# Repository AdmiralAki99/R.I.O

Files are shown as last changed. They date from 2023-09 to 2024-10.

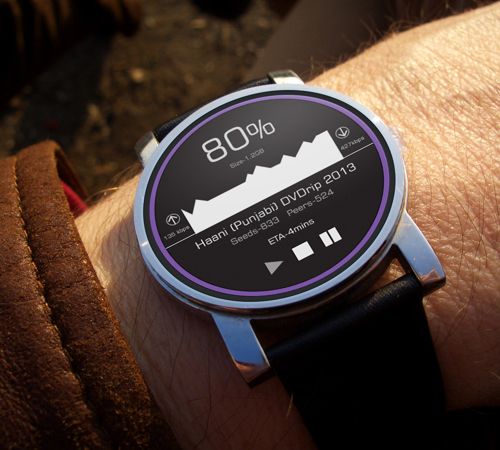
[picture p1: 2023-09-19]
src/test.jpg

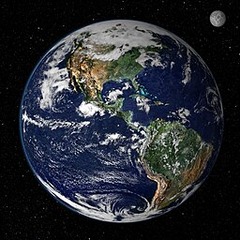
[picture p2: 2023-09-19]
src/space.jpg

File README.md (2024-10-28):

# Smartwatch Software

## Overview

A basic smartwatch software that is used for personal use and understanding how to read schematics, design PCB, understand embedded sytems.

## Render

https://github.com/user-attachments/assets/5ccf8013-91de-4bed-8570-e81a325c24fe

## Schematic
Schematic_page-0001

## Features

<ul>
    <li> BLE Communication With Swift Companion App</li>
    <li> Fits Inside 42mm Metal Watch Case </li>
</ul>

## Hardware Used
<ol>
    <li> ESP32 S3 MCU </li>
    <li> GC9A01 TFT Screen 1.28 Touch Screen </li>
    <li> Resistor (160k)</li>
    <li> Resistor (442k)</li>
    <li> 4 pin Magnetic Connector</li>
    <li> JST 2 Pin Connector RA</li>
    <li> Two Vertical Tactile Switch</li>
    <li>Schotky Diode </li>
</ol>

## Challenges Faced

<ul>
    <li> Understanding Schematics to connect the data pins and power pins to the magnetic connector to allow for flashing of the board </li>
    <li> Implementing BLE GATT Server & Characteristics</li>
    <li> Controlling power consumption to increase battery life </li>
    <li> Designing 3D housing for the watch to be placed inside the metal watch</li>
    <li> Designing PCB board using KiCad</li>
</ul>

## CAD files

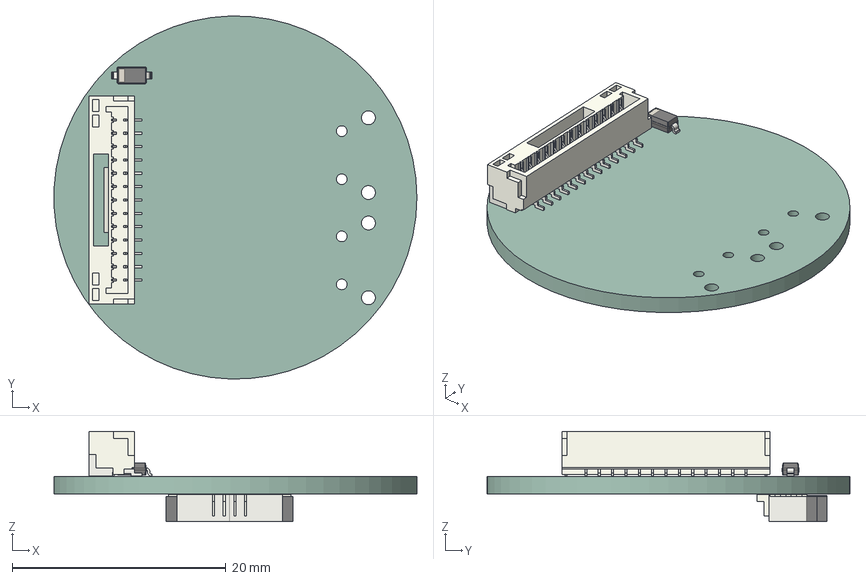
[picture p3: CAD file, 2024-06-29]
RIO_V1/RIO_V1.step
34.0 x 34.0 x 8.46 mm
JST_BM13B_GHS_TBT
D_SOD_123
TE_84952_4
RIO_V1 PCB

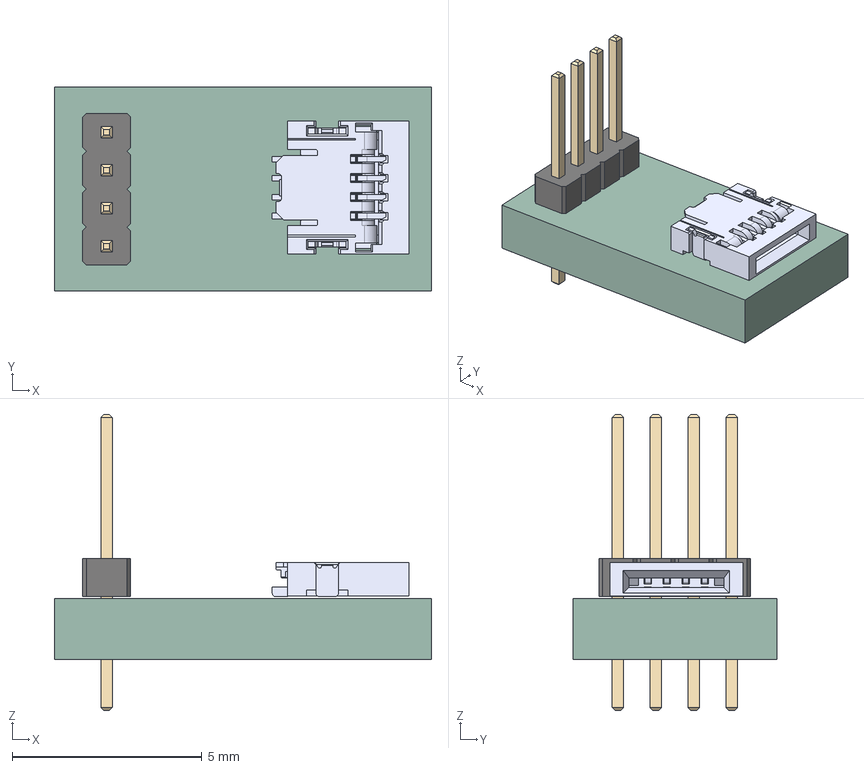
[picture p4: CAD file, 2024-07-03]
RIO_V1/Watch_Connector_V1/Watch_Connector_V1.step
9.93 x 5.38 x 7.80 mm
Watch_Connector_V1 1.1.1
PinHeader_1x04_P100mm_Vertical
Watch_Connector_V1 PCB

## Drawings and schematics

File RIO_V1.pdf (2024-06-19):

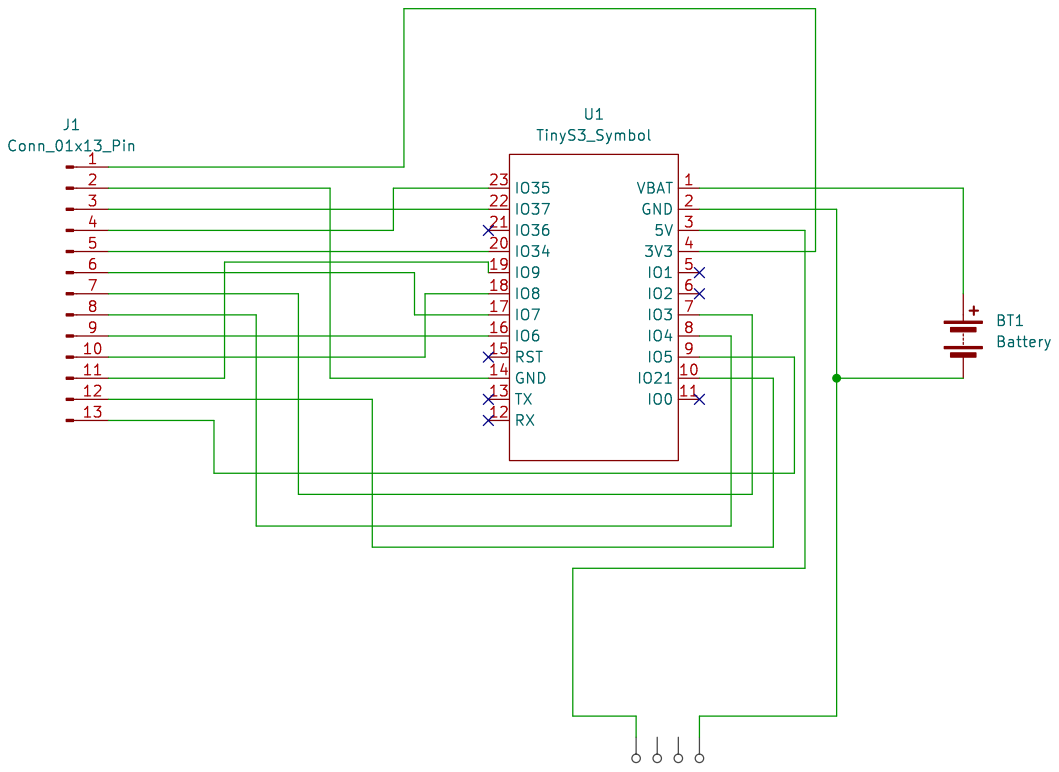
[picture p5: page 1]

Id: 1/1 Title: File: RIO_V1.kicad_sch Sheet: /

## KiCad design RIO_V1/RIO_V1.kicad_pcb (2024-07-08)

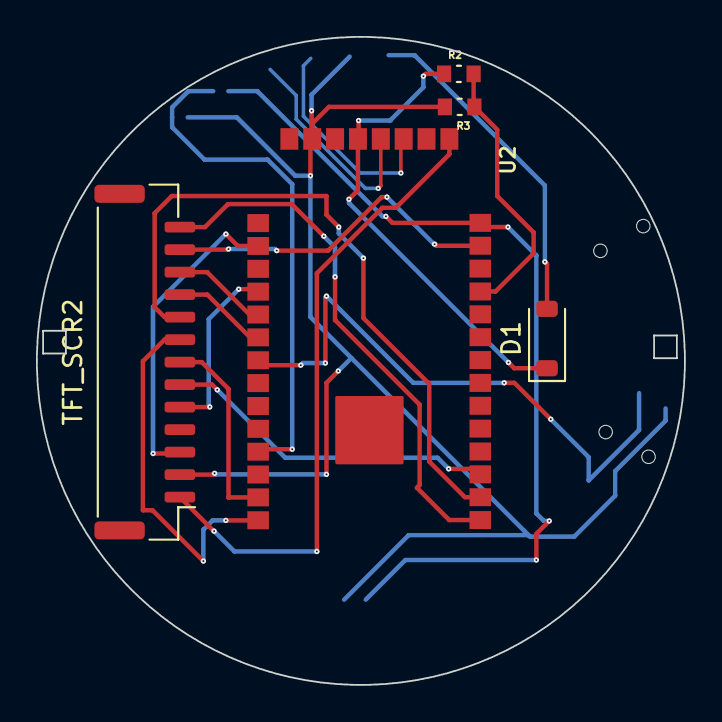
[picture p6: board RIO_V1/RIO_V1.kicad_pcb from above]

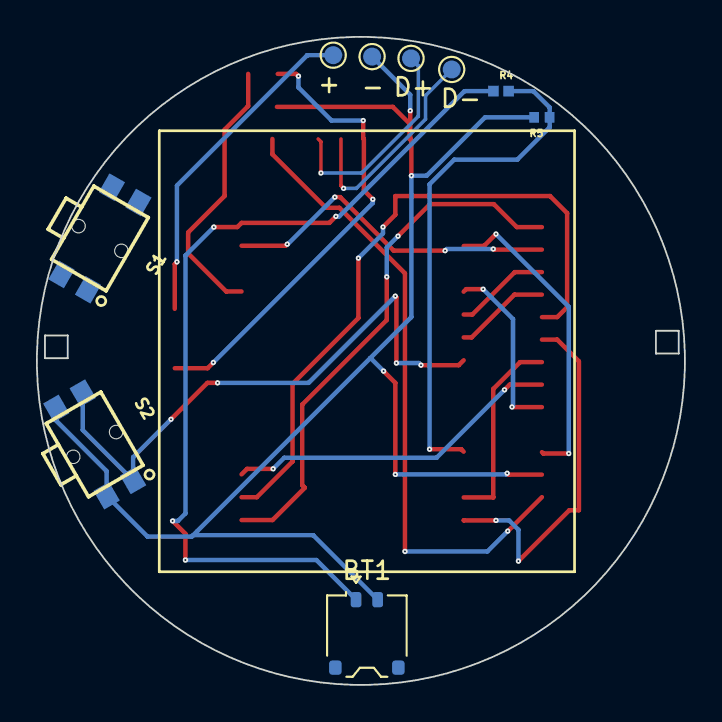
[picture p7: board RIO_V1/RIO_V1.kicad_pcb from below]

Board: 2 copper layers, 36.0 x 36.0 mm, 14 parts (9 on the bottom side), 22 nets.

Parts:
+: TestPoint; TestPoint_Pad_D1.0mm
-: TestPoint; TestPoint_Pad_D1.0mm
BT1: Battery; JST_ACH_BM02B-ACHSS-GAN-ETF_1x02-1MP_P1.20mm_Vertical
D1: MBR0530-TP; D_SOD-123
D+: TestPoint; TestPoint_Pad_D1.0mm
D-: TestPoint; TestPoint_Pad_D1.0mm
R2, R3: 50k; RESC1608X55N
R4: 442k; RESC1005X35N
R5: 160k; RESC1005X40N
S1, S2: TL1014BF160QG
TFT_SCR2: GH_CONNECTOR; JST_GH_BM13B-GHS-TBT_1x13-1MP_P1.25mm_Vertical
U2: NanoS3

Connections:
+3V3: TFT_SCR2.1, U2.8 (3v3)
+5V: D1.1 (K), R2.1, U2.4 (5V)
D+: D+.1, U2.6 (D+)
D-: D-.1, U2.5 (D-)
GND: -.1, BT1.2 (-), R3.2, R5.2, S1.1, S1.3, S2.2, S2.4, TFT_SCR2.2, U2.2 (GND)
IO0: S2.1, S2.3, U2.29 (IO0)
IO1: R4.2, R5.1, U2.33 (IO1)
IO3: TFT_SCR2.7, U2.35 (IO3)
IO4: TFT_SCR2.8, U2.36 (IO4)
IO5: TFT_SCR2.13, U2.22 (IO5)
IO6: TFT_SCR2.9, U2.21 (IO6)
IO7: TFT_SCR2.6, U2.20 (IO7)
IO8: TFT_SCR2.10, U2.28 (IO8)
IO9: TFT_SCR2.11, U2.27 (IO9)
IO17: R2.2, R3.1, U2.12 (IO17)
IO21: TFT_SCR2.12, U2.10 (IO21)
IO34: TFT_SCR2.5, U2.26 (IO34)
IO35: TFT_SCR2.4, U2.23 (IO35)
IO37: TFT_SCR2.3, U2.24 (IO37)
unnamed: +.1, D1.2 (A)
RESET: S1.2, S1.4, U2.3 (RESET)
VBAT: BT1.1 (+), R4.1, U2.9 (VBAT)

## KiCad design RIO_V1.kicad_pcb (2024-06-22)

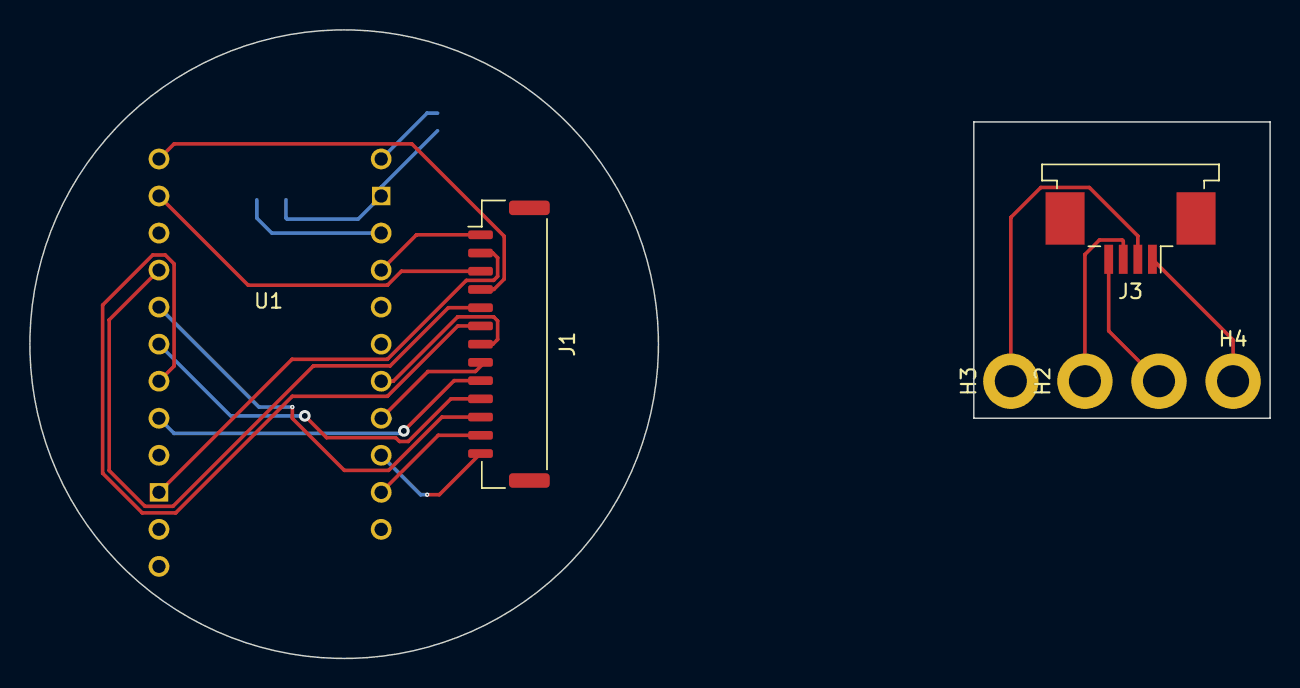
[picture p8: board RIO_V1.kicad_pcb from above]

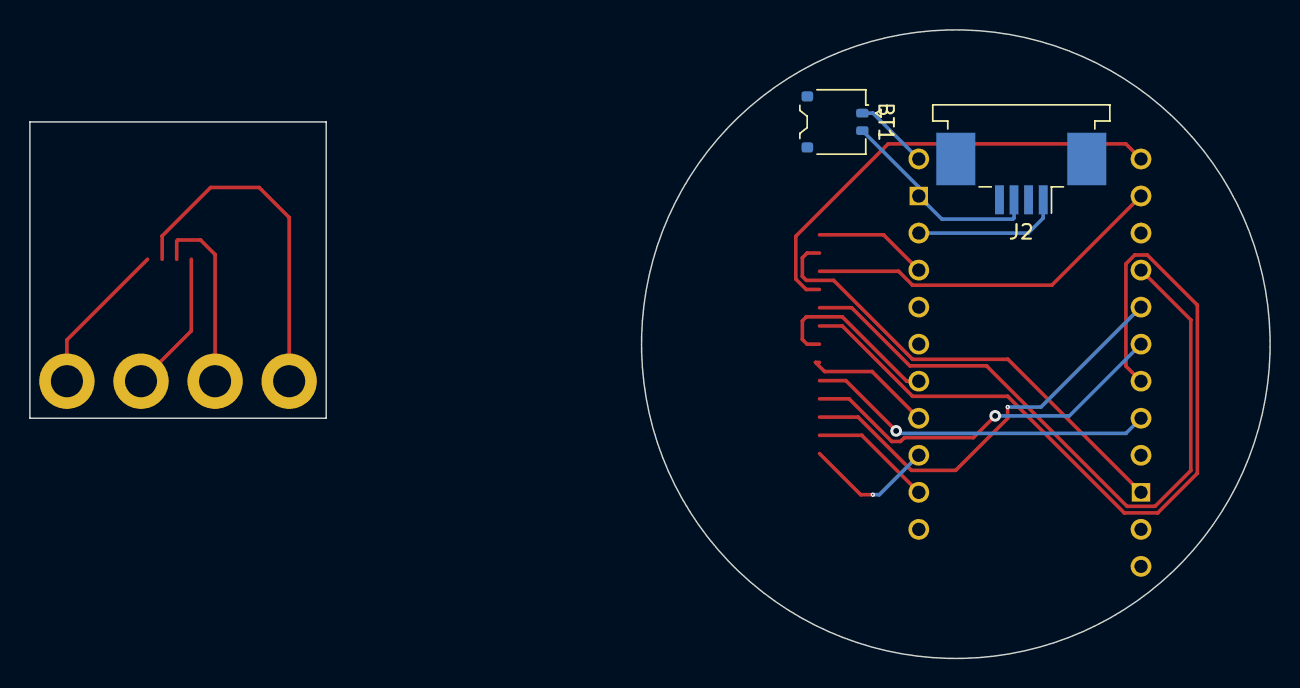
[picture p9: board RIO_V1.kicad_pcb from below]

Board: 2 copper layers, 85.1 x 43.1 mm, 9 parts (2 on the bottom side), 20 nets.

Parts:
BT1: Battery; JST_ACH_BM02B-ACHSS-GAN-ETF_1x02-1MP_P1.20mm_Vertical
H1: Pin_2; MountingHole_2.2mm_M2_DIN965_Pad
H2: Pin_3; MountingHole_2.2mm_M2_DIN965_Pad
H3, H4: Pin_4; MountingHole_2.2mm_M2_DIN965_Pad
J1: Conn_01x13_Pin; JST_GH_BM13B-GHS-TBT_1x13-1MP_P1.25mm_Vertical
J2: Conn_01x03_Pin; TE_84952-4_1x04-1MP_P1.0mm_Horizontal
J3: Conn_01x04_Pin; TE_84952-4_1x04-1MP_P1.0mm_Horizontal
U1: TinyS3_Symbol; TinyS3

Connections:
unnamed: BT1.1 (+), U1.1 (VBAT)
unnamed: BT1.2 (-), J2.3, U1.2 (GND)
unnamed: J1.1, U1.4 (3V3)
unnamed: J1.2, U1.14 (GND)
unnamed: J1.3, U1.22 (IO37)
unnamed: J1.4, U1.23 (IO35)
unnamed: J1.5, U1.20 (IO34)
unnamed: J1.6, U1.17 (IO7)
unnamed: J1.7, U1.7 (IO3)
unnamed: J1.8, U1.8 (IO4)
unnamed: J1.9, U1.16 (IO6)
unnamed: J1.10, U1.18 (IO8)
unnamed: J1.11, U1.19 (IO9)
unnamed: J1.12, U1.10 (IO21)
unnamed: J1.13, U1.9 (IO5)
unnamed: J2.1, U1.3 (5V)
unnamed: H4.1, J3.1
unnamed: H3.1, J3.2
unnamed: H2.1, J3.3
unnamed: H1.1, J3.4

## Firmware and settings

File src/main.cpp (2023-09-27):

#include "settings_screen.h"
#include "parsecs.h"
#include "time_screen.h"
#include <TFT_eSPI.h>
#include <lvgl.h>
#include <CST816S.h>
#include <driver/gpio.h>
#include <Ticker.h>
#include <WiFi.h>
#include <esp_bt.h>
#include "driver/adc.h"

time_t current_time;

void setup() {
  // put your setup code here, to run once:

  pinMode(LCD_BL_PIN,OUTPUT);

  digitalWrite(LCD_BL_PIN,HIGH);

  // touch.begin();

  // /**
  //  * Initialize the TFT_eSPI Drivers
  //  * */
  // tft.init();
  // tft.setRotation(0);

  init_watch();

  init_ble_server();

  // tft.fillScreen(TFT_WHITE);

  // xTaskCreatePinnedToCore(sendMessage(&message[0],7),"Send Message",10000,NULL,1,&bluetooth_task_handle,1);

  // tft.fillScreen(TFT_WHITE);
  // Serial.begin(115200);


  /**
   * Initialize LVGL Library and Functions
   **/

  // a2dp_sink.start("ESP32 A2DP Sink");
  // a2dp_sink.set_avrc_metadata_callback(avrc_metadata_callback);
  // lv_init();

  // // lv_disp_buf_init(&draw_buf,buf_1,NULL,240*10); 
  // lv_disp_draw_buf_init(&draw_buf, buf_1, NULL, 240 * 10);//Initialize Display Buffer

  // static lv_disp_drv_t disp_drv;
  // lv_disp_drv_init(&disp_drv);

  // disp_drv.hor_res = screenWidth;
  // disp_drv.ver_res = screenHeight;
  // disp_drv.flush_cb = flush_display;
  // disp_drv.draw_buf = &draw_buf;
  // lv_disp_drv_register(&disp_drv);

  // //todo: Add Touch Functions and Displays to LVGL

  // static lv_indev_drv_t indev_drv;
  // lv_indev_drv_init(&indev_drv);
  // indev_drv.type = LV_INDEV_TYPE_POINTER;
  // indev_drv.read_cb = touchpad_event;
  // lv_indev_t* touchpad = lv_indev_drv_register(&indev_drv);

  // // display_watch_dial(lv_scr_act());

  // // Create a style for the waveform
  // /* Create a container object */
  //   // lv_obj_t * label;


  /**
   * Creating the Background Dial Style and Button
   * */

  main_screen = lv_obj_create(NULL);
  /**
   * Creating a watch second and minute hands and hour hands
   * 
   **/
  
  current_time = time(nullptr);

  init_screen(main_screen);

  // lv_style_t transp_button;

  // lv_style_init(&transp_button);
  // lv_style_set_bg_opa(&transp_button,LV_STATE_DEFAULT,0);
  // lv_style_set_border_width(&transp_button,LV_STATE_DEFAULT,0);
  // lv_style_set_outline_width(&transp_button,LV_STATE_DEFAULT,0);

  // btn = lv_btn_create(time_screen,NULL);
  // lv_obj_align(btn,NULL,LV_ALIGN_IN_TOP_MID,0,0);
  // lv_obj_add_style(btn,LV_BTN_PART_MAIN,&transp_button);
  // lv_obj_set_style_local_bg_color(btn,LV_BTN_PART_MAIN,LV_STATE_DEFAULT,LV_COLOR_BLACK);
  // lv_obj_set_style_local_value_str(btn,LV_OBJ_PART_MAIN,LV_STATE_DEFAULT,"Button");
  // lv_obj_set_style_local_value_color(btn,LV_OBJ_PART_MAIN,LV_STATE_DEFAULT,LV_COLOR_WHITE);
  // lv_obj_set_event_cb(btn,test_cb);

  // lv_obj_t *back_icon = lv_img_create(btn, NULL);
  // lv_img_set_src(back_icon, LV_SYMBOL_LEFT);
  // lv_obj_set_size(back_icon, 20, 20);
  // lv_obj_set_pos(back_icon, 10, 5);
  // lv_obj_set_style_local_text_color(back_icon, LV_LABEL_PART_MAIN, LV_STATE_DEFAULT, LV_COLOR_WHITE); // Set the icon color to white

  // init_music_screen(main_screen);

  // init_settings_screen(main_screen);

  lv_scr_load(main_screen);
  
  gpio_config_t io_conf;
  io_conf.intr_type = GPIO_INTR_DISABLE;
  io_conf.mode = GPIO_MODE_INPUT;
  io_conf.pin_bit_mask = 1ULL <<GPIO_NUM_0;
  io_conf.pull_down_en = GPIO_PULLDOWN_DISABLE;
  io_conf.pull_up_en = GPIO_PULLUP_ENABLE;
  gpio_config(&io_conf);
  //todo: Create circular line meter for battery level

  Serial.print(touch.data.version);
  Serial.print("\t");
  Serial.print(touch.data.versionInfo[0]);
  Serial.print("-");
  Serial.print(touch.data.versionInfo[1]);
  Serial.print("-");    
  Serial.println(touch.data.versionInfo[2]);

  // lv_obj_t *img_obj = lv_img_create(lv_scr_act());

  // lv_img_set_src(img_obj,"A:src/space.jpg");

  lv_scr_load(main_screen);
  initTimer();

  // Serial.begin(115200);
  // Serial.println(xPortGetCoreID());
}

void loop() {
  // Open a large JPEG image stored in FLASH memory (included as thumb_test.h)
  // This image is 12 megapixels, but has a 320x240 embedded thumbnail in it

  // put your main code here, to run repeatedly

  // sendMessage(&message[0],7);

  // Serial.println(xPortGetCoreID());
  

  lv_scr_load(lv_scr_act());

  lv_task_handler();
  lv_timer_handler();

  current_time = now();

  update_screen(current_time);

  // Serial.println(String(touch.gesture().c_str()));

  // advertise_ble_server();


  // if(gpio_get_level(GPIO_NUM_0) == 0)
  // {
  //   Serial.println("Button Pressed");
  // }

  // if(play_button_task != NULL)
  // {
  //   // Serial.println( "Play Button Task is not NULL");
  // }else{
  //   Serial.println("Play Button Task is NULL");
  // }

  lv_tick_inc(1);
  // update_music_screen();

  // vTaskDelay(pdMS_TO_TICKS(16));

  // delay(1000);
  
}

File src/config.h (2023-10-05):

#pragma once

#include <FS.h>
#include <TFT_eSPI.h>
#include <lvgl.h>
#include <CST816S.h>
#include <driver/gpio.h>
#include <Ticker.h>
#include <WiFi.h>
#include <TinyGPSPlus.h>
#include <SoftwareSerial.h>
#include <TimeLib.h>

#include "freertos/FreeRTOS.h"
#include "freertos/task.h"

#include "ble_config.h"

#define LV_COLOR_BLACK  LV_COLOR_MAKE(0x00, 0x00, 0x00)
#define LV_COLOR_WHITE LV_COLOR_MAKE(0xFF, 0xFF, 0xFF)
#define LV_COLOR_GREY LV_COLOR_MAKE(0x80, 0x80, 0x80)

#define SERVICE_UUID "4fafc201-1fb5-459e-8fcc-c5c9c331914b"
#define CHARACTERISTIC_UUID "beb5483e-36e1-4688-b7f5-ea07361b26a8"
#define TIME_CHARACTERISTIC_UUID "b9dc3d38-4b22-11ee-be56-0242ac120002"
#define TODO_CHARACTERISTIC_UUID "28bd3c28-635d-11ee-8c99-0242ac120002"

/**
 * Pin Definitions for GC9A01 TFT SCREEN
*/

#define MISO_PIN 37
#define MOSI_PIN 35
#define SCLK_PIN 34
#define LCD_CS_PIN 7
#define LCD_DC_PIN 3
#define LCD_RST_PIN 4
#define LCD_BL_PIN 6
#define TP_SDA_PIN 8
#define TP_SCL_PIN 9
#define TP_INT_PIN 21
#define TP_RST_PIN 5

/**
 * Pin Definitions for the GPS Module
*/

#define GPS_RX_PIN 2
#define GPS_TX_PIN 36

/**
 * Declaring the Global Variables that will be used commonly
*/

lv_obj_t* main_screen;

TinyGPSPlus gps = TinyGPSPlus();
SoftwareSerial ss(GPS_RX_PIN, GPS_TX_PIN);

#define ANALOG_WATCH_FACE

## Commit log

2023-09-19 Fixed Bug
    Removed bug that stopped interaction
    [main.cpp]
2023-09-24 Added Method to Signal State of Music Playback
    Added simple method to send music playback to device to indicate if track needs to be skipped or rewinded. Need to create method to encode message and decode encoded messages
    [music_screen.h, parsecs.h]
2023-09-26 Created Video Source enum class
    Created Video Source enum class to track state of playback
2023-09-26 Fixed System Error
    Fixed system error that did not left Touch screen to be drawn
    [parsecs.h]
2023-09-27 Created a 200x200 to display frames
    Created a 200x200 canvas to display frames. Size restricted due size of RAM available. Need to try projecting decoded JPEG images
2023-10-02 Removed and Changed BLE Functionality
    Removed and changed BLE functionality to remove the initial values as well as remove the case where my mistake caused multiple transmissions to App
    [parsecs.h]
2023-10-02 Changed Function Calls to Display Metadata
    Changed function calls to change the way the music metadata is displayed on the device and removed the error where music labels were concatenated instead of repalced
    [music_screen.h]
2023-10-04 Added Functionality To Receive Tasks Over BLE
    Added functionality to add tasks over BLE and display them accordingly. The current limits for the tasks is 20 tasks for now.
2023-10-04 Reduced Response Time
    Reduced response time from the Apps side, need to store the states of each task in order to get the current status of the task correctly
2023-10-05 Important: Last Stable Checkpoint
    Added New BLE Callback for Todo State. Will only be able to test entire project instead of components after board is replaced.
    [config.h, parsecs.h]
2023-10-06 Added Task Status Checking For Checkboxes
    Added task status checking for checkboxes so that the current status of the tasks
2024-06-19 KiCad Schematics & PCB Design
    KiCad Schematics & PCB Design for the board that will be housed in the casing
    [RIO_V1.kicad_pcb, RIO_V1.kicad_sch]
2024-06-19 PDF Version of KiCad Schematic For Documentation
    PDF version of KiCad Schematic for documentation to be used for reference going forward and work on adding upgrades to it later
2024-06-22 Updated Schematics & PCB To Incorporate Connector
    Updated Schematic and PVB to incorporate the JST Connector instead of resodering it with a TE FPC connector
    [RIO_V1.kicad_pcb, RIO_V1.kicad_sch]
2024-06-27 Changed TinyS3 To NanoS3
    [RIO_V1.kicad_sch]
2024-06-29 Added KiCad Files To Folders
    Added new KiCad Schematics and PCB designs for both the main PCB as well as the magnetic POGO connector PCB in the project
    [RIO_V1.kicad_pcb, RIO_V1.kicad_sch, RIO_V1.step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]
2024-06-30 Added Charging Sense Circuit
    Added charging sense circuit to allow for detecting if the circuit is turned on using an IO pin on the MCU
    [RIO_V1.kicad_sch]
2024-07-02 Updated Symbols Footrprints and Routing
    Updated the symbols, footprints and the PCB routing to work with the new resistors and ADC circuit
    [RIO_V1.kicad_pcb, RIO_V1.kicad_sch]
2024-07-03 Changed The FPC Connector To A Smaller Pitch
    Changed the FPC connector on the PCB so that the pitch is reduced and overall footprint is minimized as much as possible
    [RIO_V1.kicad_pcb, RIO_V1.kicad_sch, Watch_Connector_V1.kicad_pcb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]
2024-07-08 Added New PCB Conenctors, Routes, Components
    Added new PCB components to reduce the height, changed the traces and adjusted for the battery in the PCB
    [RIO_V1.kicad_pcb, RIO_V1.kicad_sch]
